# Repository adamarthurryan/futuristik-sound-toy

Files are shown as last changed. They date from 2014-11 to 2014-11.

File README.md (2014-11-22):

noise-and-light-synth
=====================

A simple noise synth with oscillators and feedback through flashing LEDS. Was presented in a series of workshops in Montreal, 2010 - 2012.

See documentation of the workshops here: http://madanworb.com/blog/2013/01/16/bleeps-workshop/

# Files:

- boards/sheet.png - a ready-to-burn 4 board layout (suitable for transferring to a 6"x4" photosensitive copper board) with some cool imagery built into the copper ground plane
- boards/a v2 traces plane.png - a ready-to-burn single board layout with a boring old ground plane
- docs/kit insert.png & docs/description.rtf - handout materials for the Eastern Block workshop, Montreal, 2012
- docs/layout.pdf - a stuffing diagram
- docs/schematic.pdf - the circuit diagram
- docs/digikey order.txt - a sample BOM for 23 complete kits
- eagle/project - the eagle project files

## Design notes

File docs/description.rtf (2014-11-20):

Workshop 1 - Schematics and prototyping

Length: 3 - 4 hours

Size: to 15 participants

Materials: breadboard
9V battery and clip
LED lights
photoresistors
various ICs, resistors, capacitors
hobby speaker
= approximately $20

Objectives: introduce basic components
read circuit schematics
introduce the concept of electronic oscillator
prototype a number of simple circuits (flashing lights, audio buzzer, modulated buzzers)

Description: Participants will build simple sound-generating circuits that make beeps, buzzes, bloops, blarps, bwaaps, etc.

No prior experience with electronics is required. Seriously! We'll learn to interpret schematic diagrams and translate them into breadboard prototypes. Experimentation is encouraged and by the end, everyone will have created a one-of-a-kind synthesizer.

Workshop 2 - Soldering

Length: 3 hours

Size: to 15 participants

Materials: custom PCB
9V battery and clip
LED lights
photoresistors
various ICs, resistors, capacitors
hobby speaker
= approximately $20

Objectives: learn soldering skills
assemble a simple working audio synthesizer / sound toy

Description: Participants will learn basic soldering techniques while assembling a futuristic light- controlled synthesizer. Shine a light on it. Put it in front of a candle. Make it go blip or bleep. You can keep what you make and amaze your friends.

No prior experience with electronics or soldering is required.

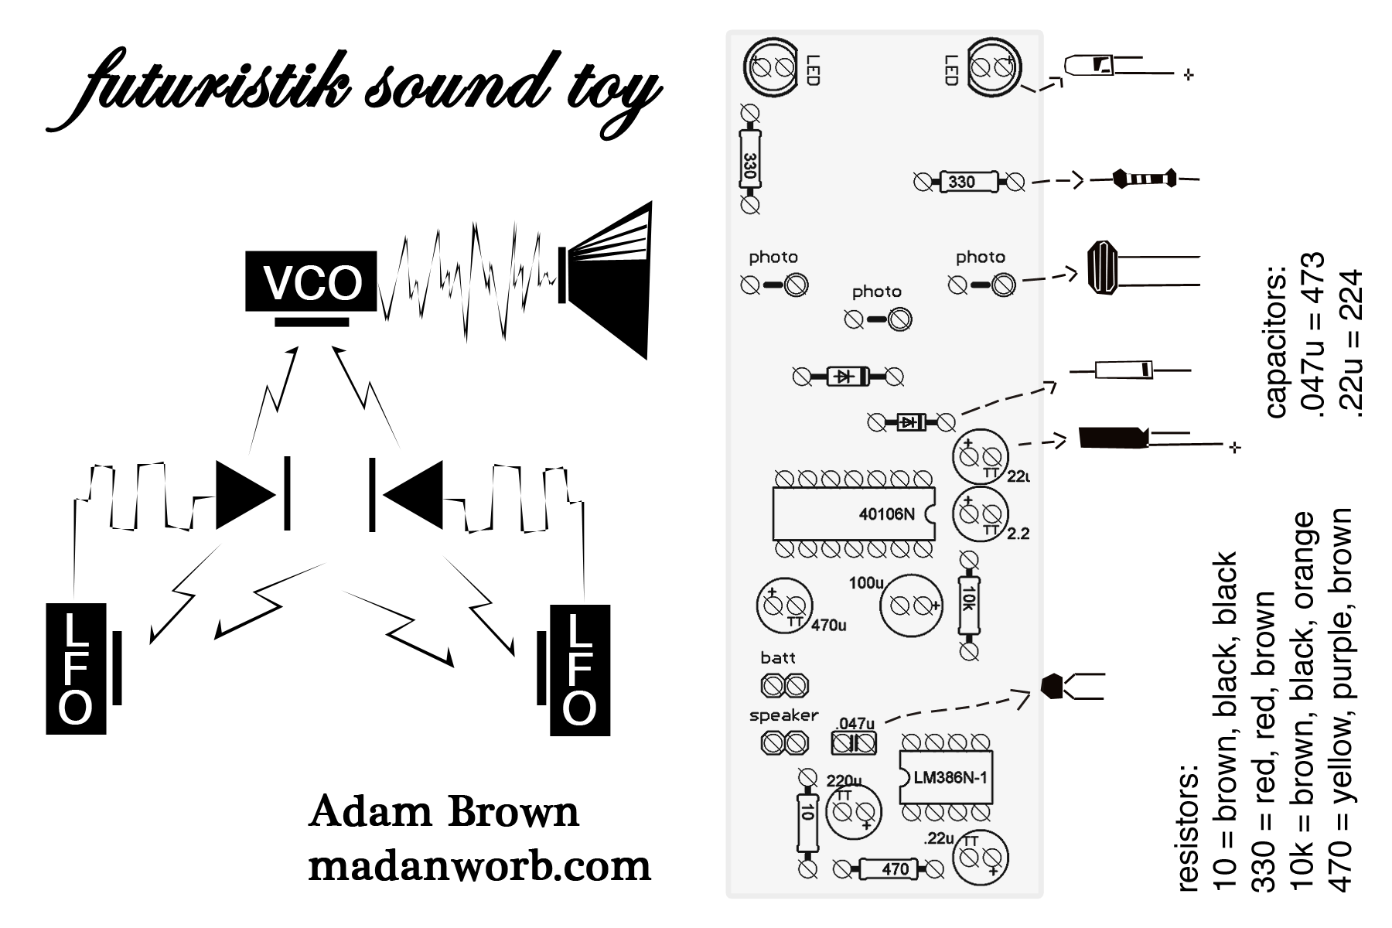
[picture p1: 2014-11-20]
docs/kit insert.png

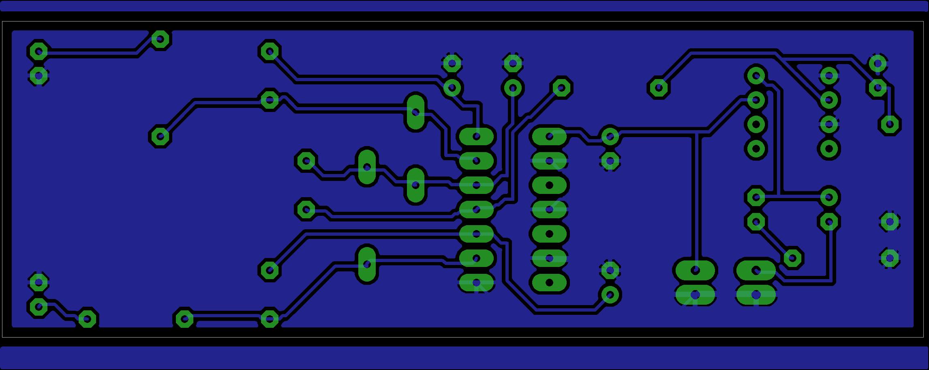
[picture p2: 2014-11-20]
boards/a v2 - traces plane.png

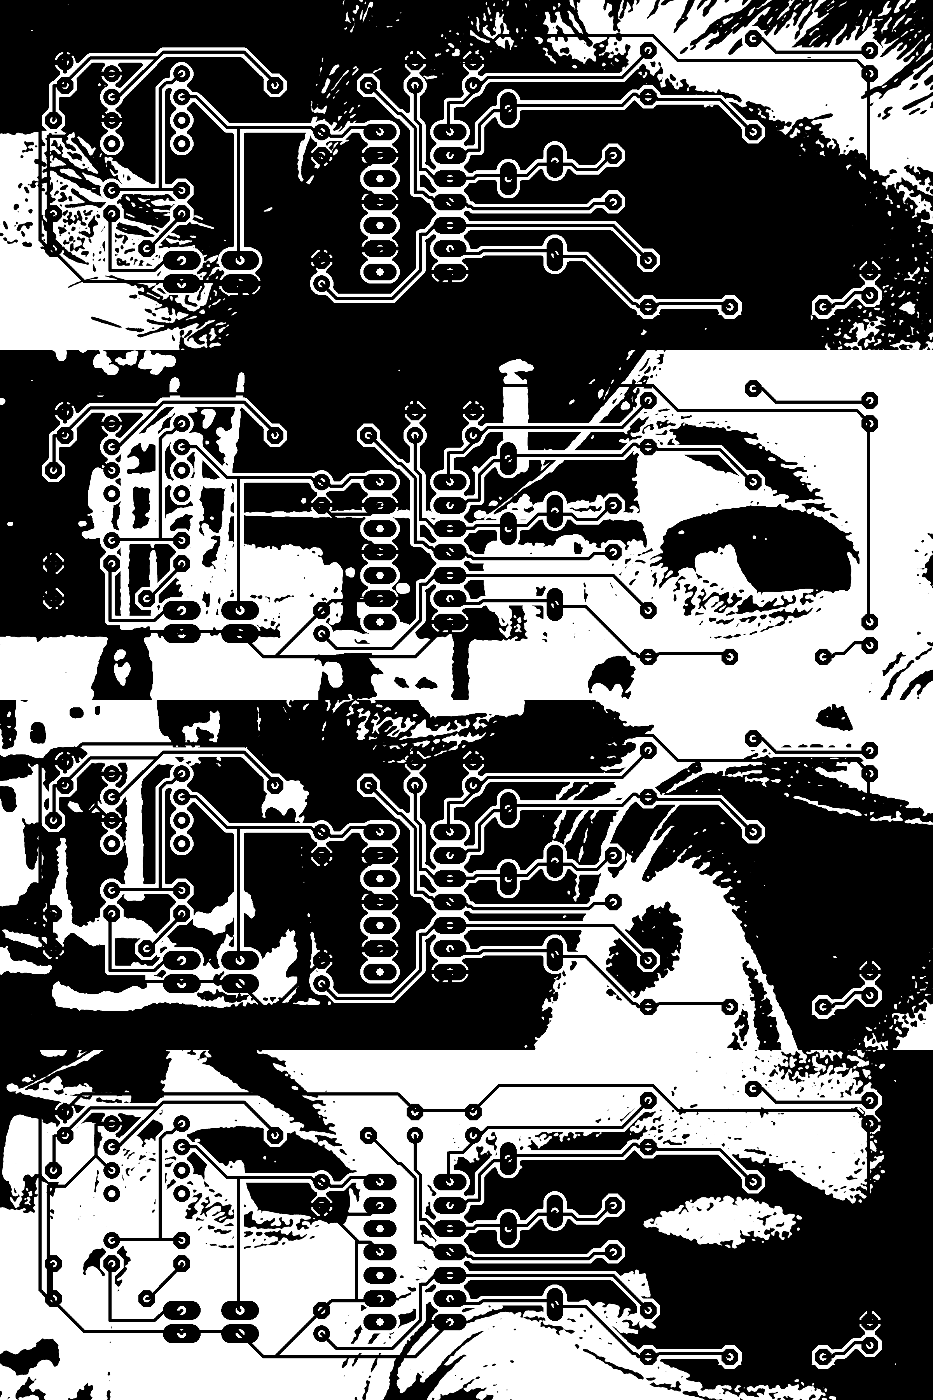
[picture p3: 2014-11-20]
boards/sheet.png

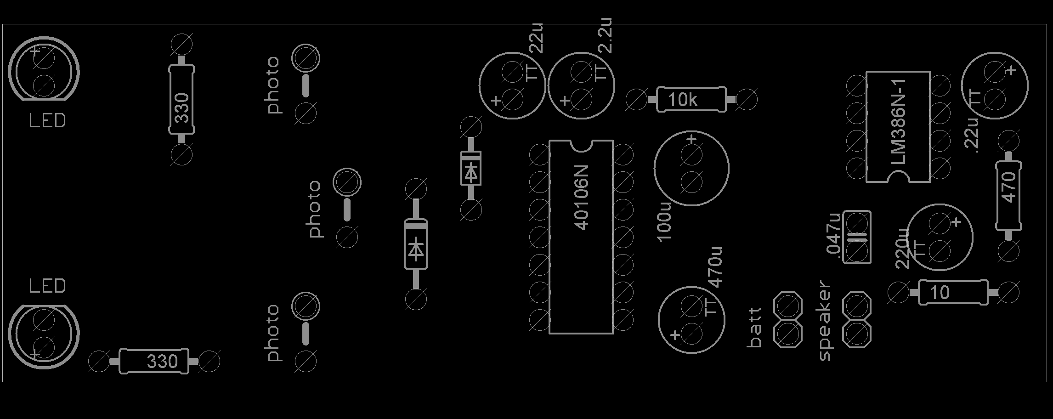
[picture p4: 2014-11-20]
boards/a v2 - labels.png

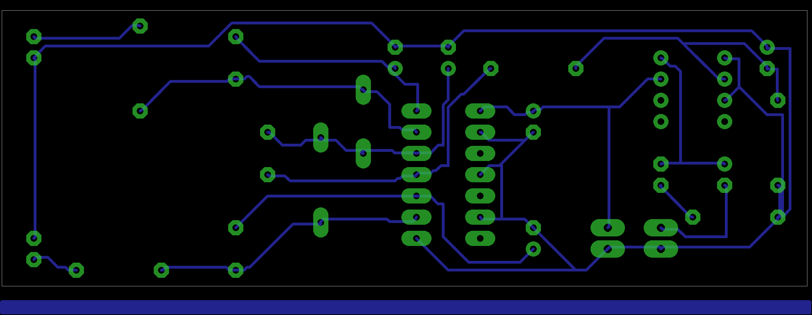
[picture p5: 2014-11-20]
boards/a v2 - traces all.png

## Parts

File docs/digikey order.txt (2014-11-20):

Digikey order for workshop at Eastern Block 14/04/2012

69	PDV-P8103-ND	photocell
13	67-2063-ND		turquoise
13	67-2064-ND		purple
13	67-2062-ND		pink
13	C503B-BCS-CV0Z0461-ND	blue
22	1N4148TACT-ND	1N4148
22	P971-ND	2.2u
22	P807-ND	10u
22	P808-ND	22u
22	P833-ND	100u
44	P5139-ND	220u
22	P5141-ND	470u
22	490-5400-ND	.047u
22	445-2849-ND	.22u
22	10KQBK-ND	10K
22	470QBK-ND	470
44	330QBK-ND	330
22	10QBK-ND	10
22	A100204-ND	DIP 8POS
22	A100205-ND	DIP 14POS
22	BS6I-MC-ND	9V snap
22	458-1135-ND	speaker
25	568-1681-5-ND	hex inverter
25	LM386N-4-ND	audio power amp
22	P647-ND	9V battery

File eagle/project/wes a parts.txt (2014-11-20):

Bill of Materials from main.sch, 23 parts, grouped by values, as of 1/9/2012 9:30:32 PM

Part			Value		Description
C1			.047u		CAPACITOR, European symbol
C2			2.2u		POLARIZED CAPACITOR, European symbol
C3			100u		POLARIZED CAPACITOR, European symbol
C4			22u		POLARIZED CAPACITOR, European symbol
C5			470u		POLARIZED CAPACITOR, European symbol
C6			.22u		POLARIZED CAPACITOR, European symbol
C7			220u		POLARIZED CAPACITOR, European symbol
D3			 		DIODE
D5			 		DIODE
IC1			40106N		Hex SCHMITT TRIGGER
IC3			LM386N-1	Low Voltage Audio Power Amplifier
LED1, LED2		 		LED
PHOTO1, PHOTO2, PHOTO3	 		RESISTOR, European symbol
PWR, SPEAKER		 		PIN HEADER
R1			470		RESISTOR, European symbol
R2, R3			330		RESISTOR, European symbol
R4			10k		RESISTOR, European symbol
R15			10		RESISTOR, European symbol

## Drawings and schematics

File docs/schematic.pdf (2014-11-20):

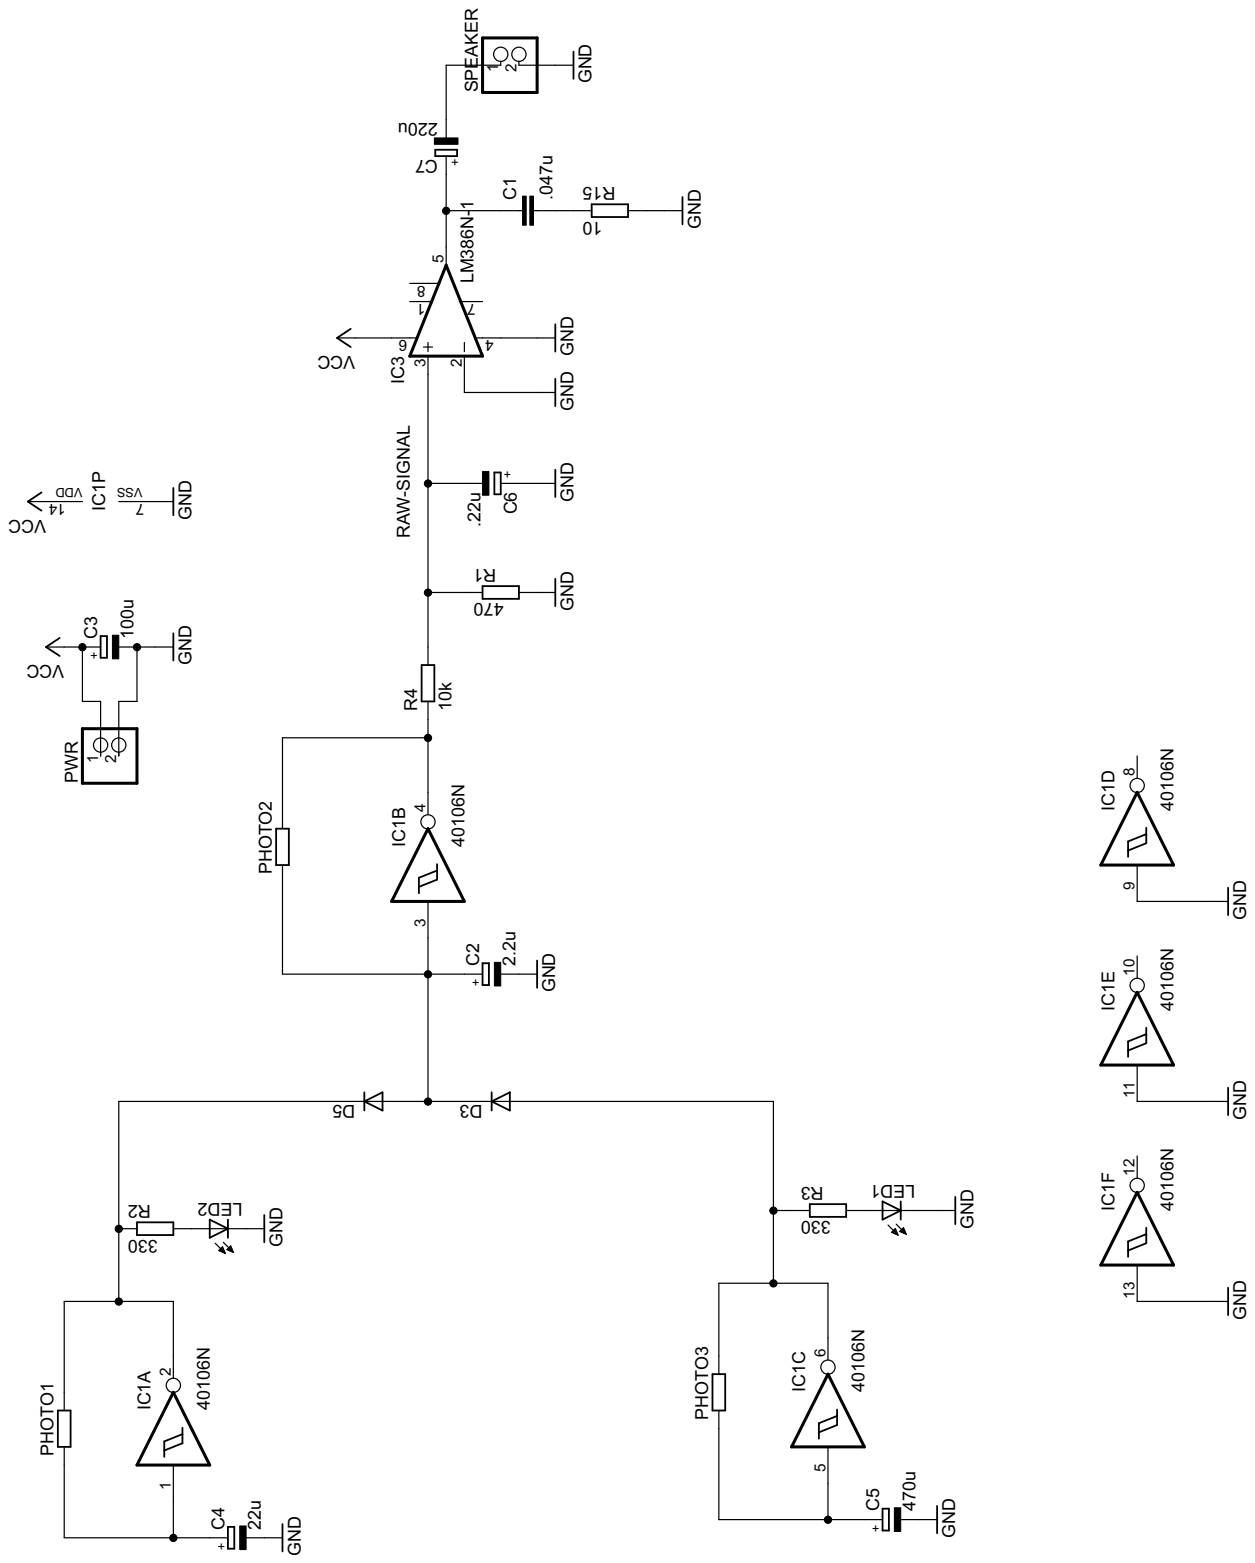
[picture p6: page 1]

40106N 40106N 40106N 40106N 40106N 40106N 100u CCV GND CCV GND GND GND 10k GND GND GND LM386N-1 GND GND .047u u022 01 CCV GND GND 2.2u 22u470u GND 074 GND 033 033 .22uGND GNDGND IC1A 1 2 IC1B 3 4 IC1F 13 12 IC1C 5 6 IC1E 11 10 IC1D 9 8 IC1DDV PSSV 41 7 C3 PWR12 R4 IC3 132 8 5 6 4 7 C1 7C 51R SPEAKER 12 C2 C4C5 PHOTO3 PHOTO1 PHOTO2 5D 3D1R 1DEL 2R 2DEL 3R C6 RAW-SIGNAL + + + + + +

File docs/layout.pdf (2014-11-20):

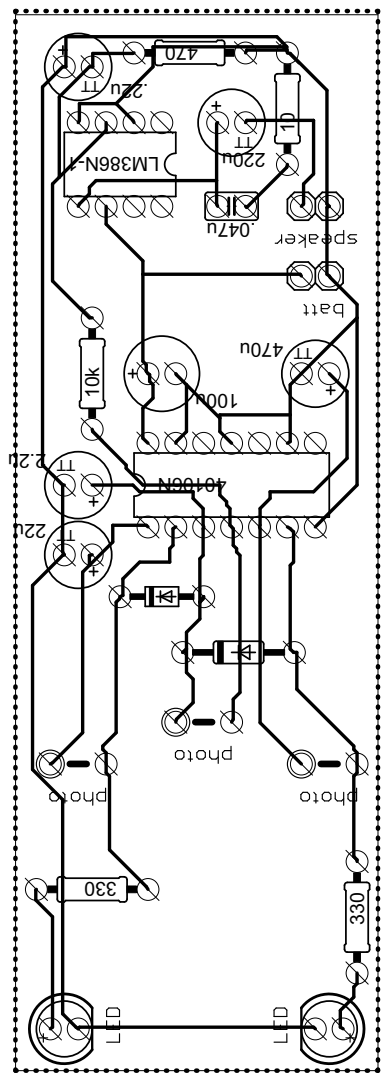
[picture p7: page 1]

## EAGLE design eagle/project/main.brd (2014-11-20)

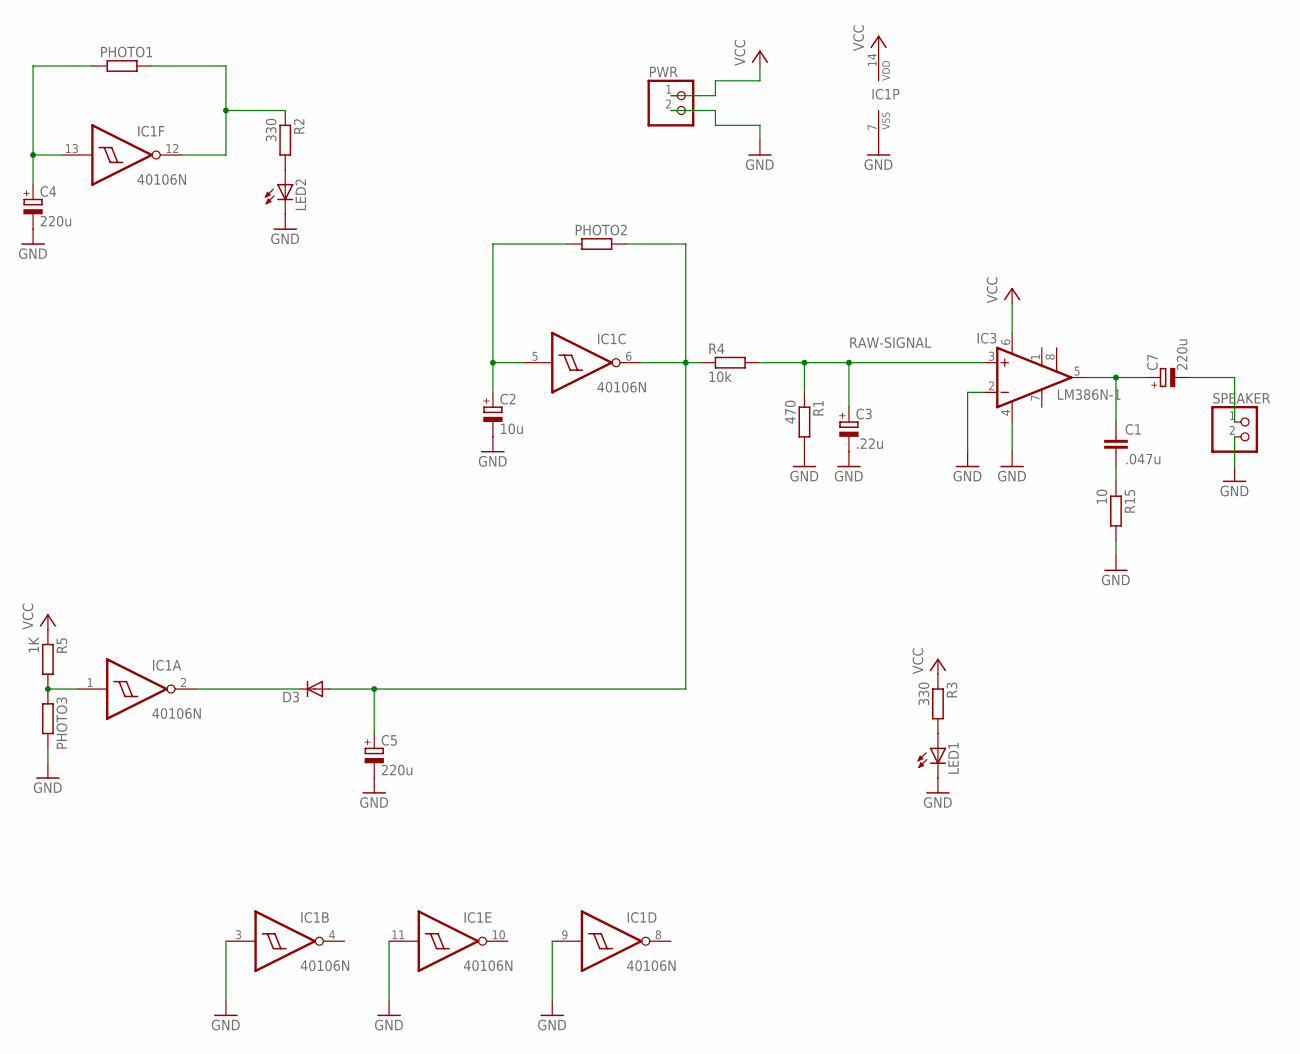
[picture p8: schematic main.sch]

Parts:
C1: .047u; C025-025X050
C2: 10u; TT2D6
C3: .22u; TT2D6
C4, C5, C7: 220u; TT2D6
D3: DIODE-DO35-10; DO35-10
IC1: 40106N; DIL14
IC3: LM386N-1; DIL08
LED1, LED2: LED5MM
PHOTO1, PHOTO2, PHOTO3: R-EU_0207/5V; 0207/5V
PWR: PINHD-1X2STRAIGHT; 1X02
R1: 470; 0207/10
R2, R3: 330; 0207/10
R4: 10k; 0207/10
R5: 1K; 0207/10
R15: 10; 0207/10
SPEAKER: PINHD-1X2STRAIGHT; 1X02

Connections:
GND: C2.-, C3.-, C4.-, C5.-, IC1.3 (I), IC1.7 (VSS), IC1.9 (I), IC1.11 (I), IC3.2 (-IN), IC3.4 (GND), LED1.K (C), LED2.K (C), PHOTO3.2, PWR.2, R1.2, R15.2, SPEAKER.2
unnamed: LED2.A, R2.2
unnamed: C2.+, IC1.5 (I), PHOTO2.1
unnamed: C4.+, IC1.13 (I), PHOTO1.1
unnamed: LED1.A, R3.2
unnamed: IC1.12 (O), PHOTO1.2, R2.1
unnamed: IC1.1 (I), PHOTO3.1, R5.2
unnamed: C5.+, D3.A, IC1.6 (O), PHOTO2.2, R4.1
unnamed: D3.C, IC1.2 (O)
unnamed: C1.1, C7.+, IC3.5 (OUT)
unnamed: C1.2, R15.1
OUT-SIGNAL: C7.-, SPEAKER.1
RAW-SIGNAL: C3.+, IC3.3 (+IN), R1.1, R4.2
VCC: IC1.14 (VDD), IC3.6 (VS), PWR.1, R3.1, R5.1

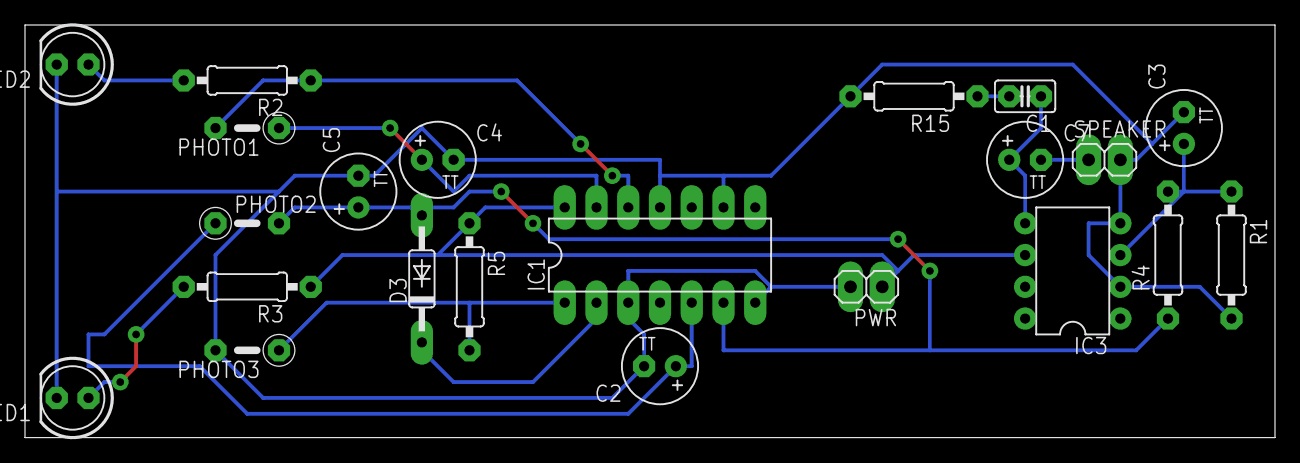
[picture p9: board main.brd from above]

Board: 2 copper layers, 100.0 x 33.0 mm, 22 parts (0 on the bottom side), 14 nets.

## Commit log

2014-11-20 initial check in of design files
    [main.brd, main.sch]
2014-11-20 updated eagle project files, added schematic rendering
2014-11-20 rename for clarity
    [main.brd, main.sch]
